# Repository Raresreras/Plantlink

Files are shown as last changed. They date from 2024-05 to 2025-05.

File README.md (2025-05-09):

# Plantlink

## :wrench: English

### Description

Planlink is a special network built to automate and increase efficiency of agriculture, indiferent of its scale. This system is composed from a receiver, which drives an irrigation system that has the capability to extract water from ground(with a better pump) and enrich it using various fertilizers, and a stand-alone sensor, which transmits its own data or relays data from other sensors.
This project has been built for the InfoEducatie 2024 competition.

### Tehnologies used

The following components and modules have been used
  + Arduino Nano
  + 433MHz Transceiver
  + DHT11 Sensor
  + Capacitive sensor to measure the soil humidty
  + TP4056
  + HW668
  + LM2596
  + IRF 840 mosfets
  + BC327 transistors
  + BC337 transistors
  + 20K resistors

Alongisde these components, there also has been used
  + 18650 batteries
  + 1W solar panel 
  + 5V water pump

The case has been 3d printed using PLA, but the use of ABS or PETG is higly recommended due to its superior thermical properties.

## :nut_and_bolt: Romanian

### Descriere

Plantlink este o rețea special concepută pentru automatizarea și eficientizarea agriculturii, indiferent
de dimensiunea acesteia. Acest sistem este format dintr-un receptor, ce conduce un sistem de irigare
ce are capabilitatea de a extrage apă din sol dar și de a-i îmbunătăți proprietățile chimice autonom, și
cel puțin un senzor autonom, ce poate transmite propriile date sau retransmite date de la alte module
senzor.
Acest proiect a fost construit pentru concursul InfoEducatie 2024. 

### Tehnologii

Au fost folosite următoare module și componente
  + Arduino Nano
  + Receptor și transmițător 433MHz
  + DHT11
  + Senzor capacitativ pentru umiditatea solului v2.0
  + TP4056
  + HW668
  + LM2596
  + IRF 840
  + BC327
  + BC337
  + Rezistori cu valoarea 20K

Pe lângă acestea, au mai fost folosite și
  + Baterii 18650
  + Panou solar 1W
  + Pompe de apă 5V

Carcasa este realizată la o imprimantă 3D folosind plastic PLA, dar se recomanda utilizarea ABS-ului sau PETG-ului datorită proprietăților termice superioare.

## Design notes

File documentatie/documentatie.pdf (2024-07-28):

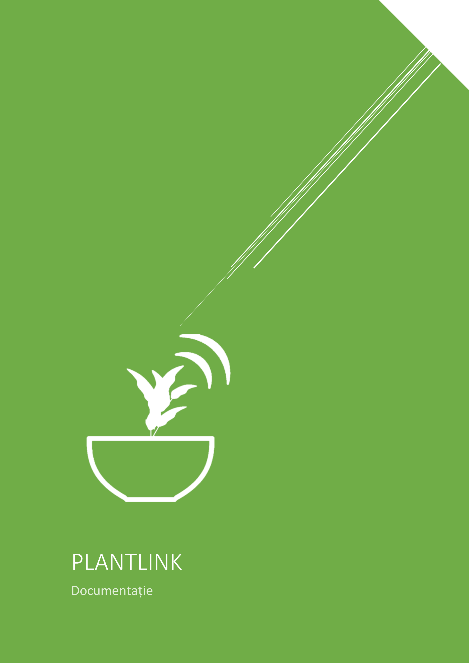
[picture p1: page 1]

# PLANTLINK

Documentație

## Introducere

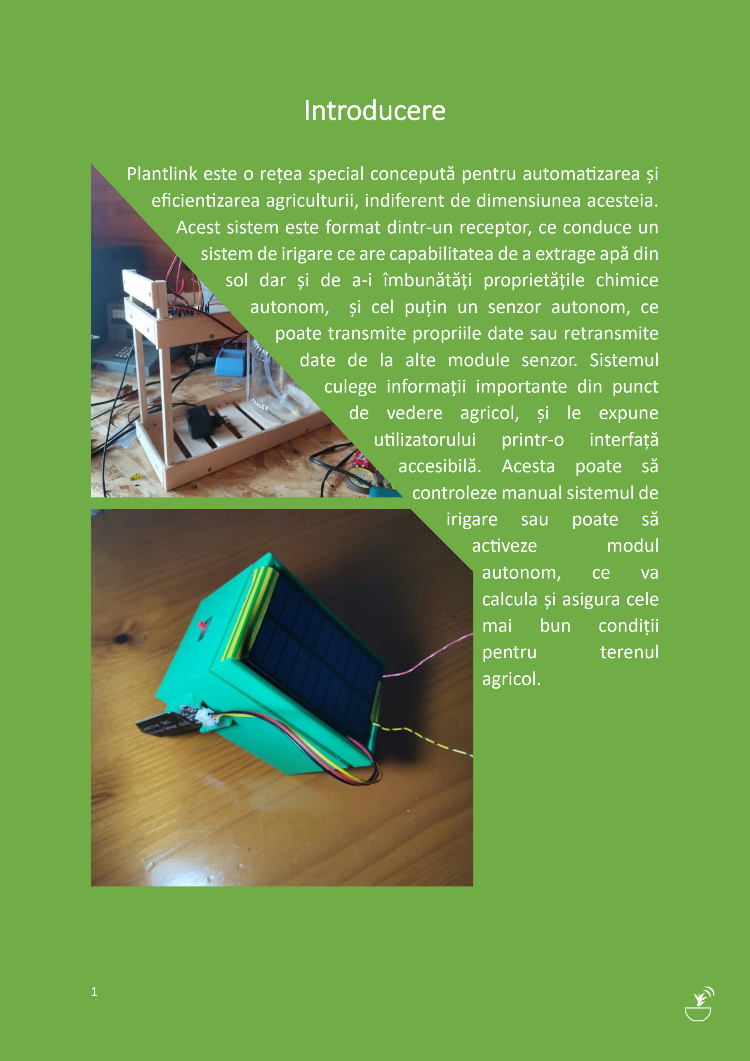
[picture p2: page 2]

Plantlink este o rețea special concepută pentru automatizarea și eficientizarea agriculturii, indiferent de dimensiunea acesteia. Acest sistem este format dintr-un receptor, ce conduce un sistem de irigare ce are capabilitatea de a extrage apă din sol dar și de a-i îmbunătăți proprietățile chimice autonom, și cel puțin un senzor autonom, ce poate transmite propriile date sau retransmite date de la alte module senzor. Sistemul culege informații importante din punct de vedere agricol, și le expune
utilizatorului | printr-o | interfață
accesibilă. Acesta poate să controleze manual sistemul de irigare sau poate să
activeze | modul
autonom, | ce | va
calcula și asigura cele
mai | bun | condiții
pentru | terenul
agricol.

## Senzorul

Senzorul este realizat pe baza unei plăci Arduino Nano, ce este conectată la un senzor DHT11 pentru înregistrarea temperaturii și umidității aerului. Pentru măsurarea umidității solului a fost folosit un modul higrometru capacitativ, datorită rezistenței sale mărite în comparație cu unul rezistiv. Senzorul poate comunica cu alți senzori din rețea sau cu receptorul principal cu ajutorul modulelor de emisie și recepție RF 433 MHz. Datorită frecvenței scăzute (în comparație cu 2.4 GHz, cea a unui modul WI-FI) senzorii au o distanță de comunicare ridicată și au caracteristici de penetrare a obstacolelor ridicate(frunze, copaci, tulpine etc.). Pentru asigurarea alimentării senzorului au fost folosite 2 module HW668, unul pentru stabilizarea tensiunii de la panoul solar și celălalt pentru ridicarea tensiunii de la bateria 18650. Pentru a asigura o exploatare sigură și longevivă a acumulatorului, a fost folosit modulul TP4056. Carcasa a fost realizată în Fusion 360 și a fost imprimată folosind plastic PLA.

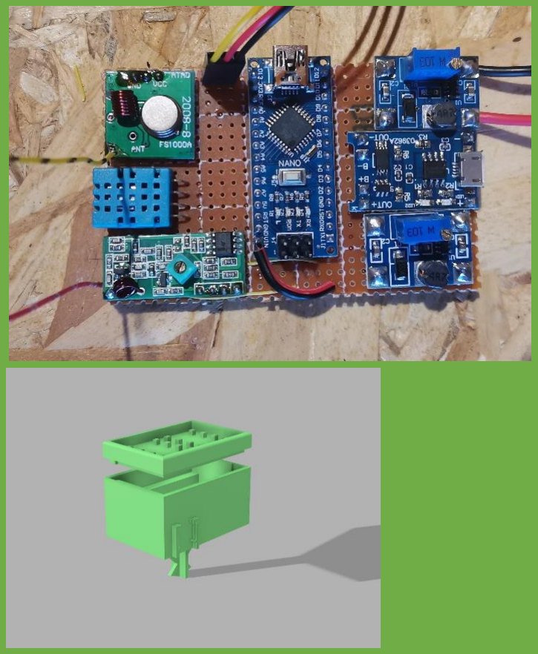
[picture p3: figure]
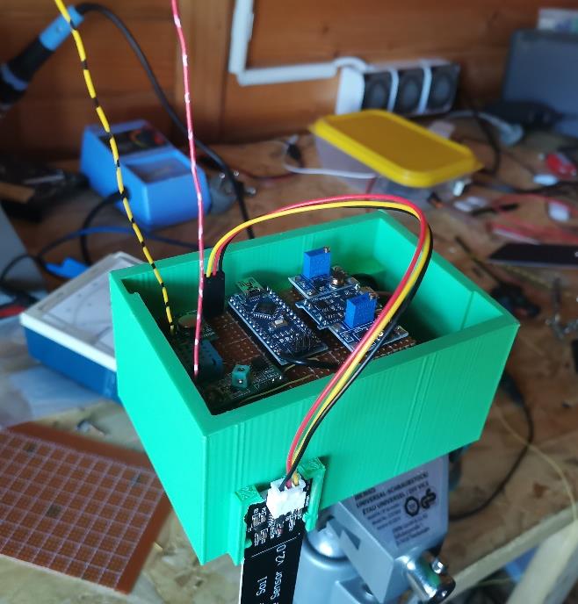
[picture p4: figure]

## Receptorul

La baza receptorului se află o placă Arduino Nano, ce obține nivelul de apă din rezervoare cu ajutorul modulelor higrometrice capacitative și comunică cu modulele senzor cu ajutorul modulelor de emisie și recepție RF 433 MHz. Puterea cu care sunt conduse pompele provine de la un modul de scădere a tensiunii LM2596 pentru a asigura o sursă de energie puternică și eficientă. Pentru a putea acționa motoarele electrice eficient și precis folosim MOSFET-urile cu canal N IRF840 și 2 tranzistori BC327 și BC337 pentru conducerea rapidă a acestuia.

Datele sunt captate de calculator prin ajutorul unui program scris în Python, ce citește un port serial USB prin ajutorul librăriei pySerial și afișează datele într-o interfață GUI creată cu PyQt6. Pentru a folosi acest program, trebuie instalat Python 3.10.5 și pachetul PyQt6.

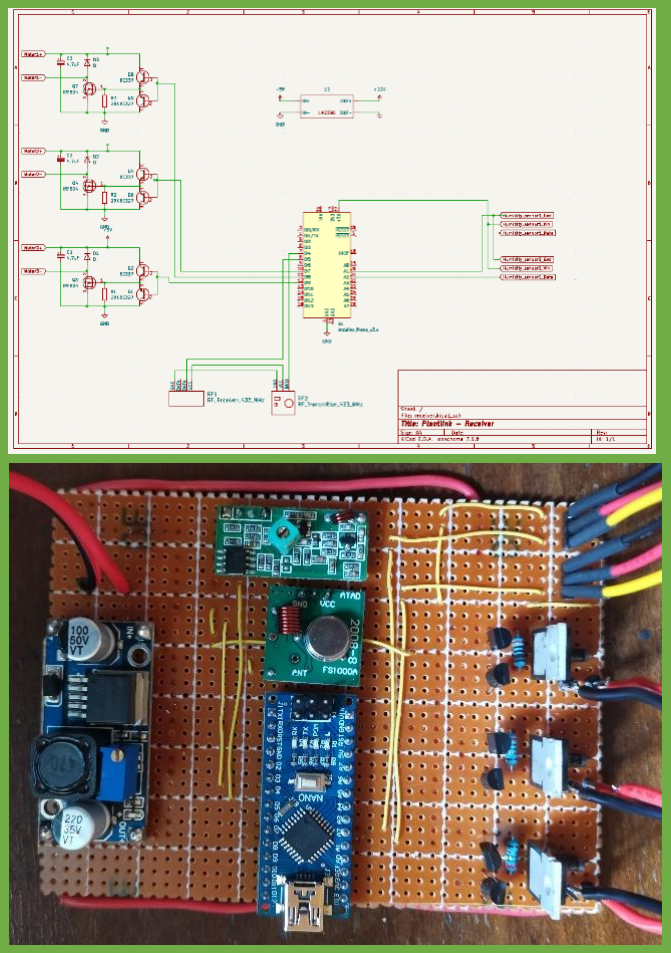
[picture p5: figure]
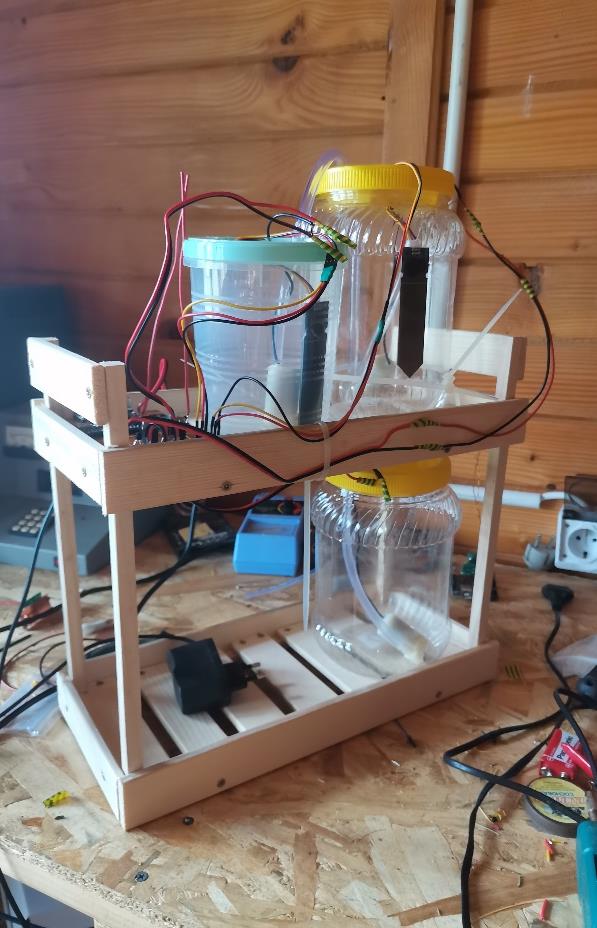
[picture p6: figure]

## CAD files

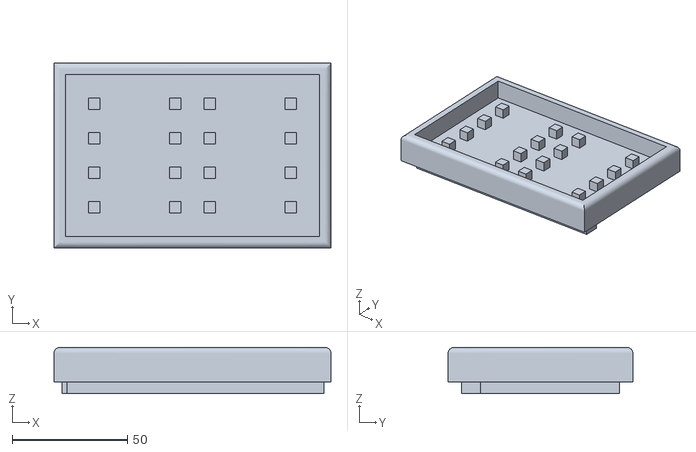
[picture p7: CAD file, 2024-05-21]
sensor v1/Plantlink cap v2.stl
120.0 x 80.0 x 20.0

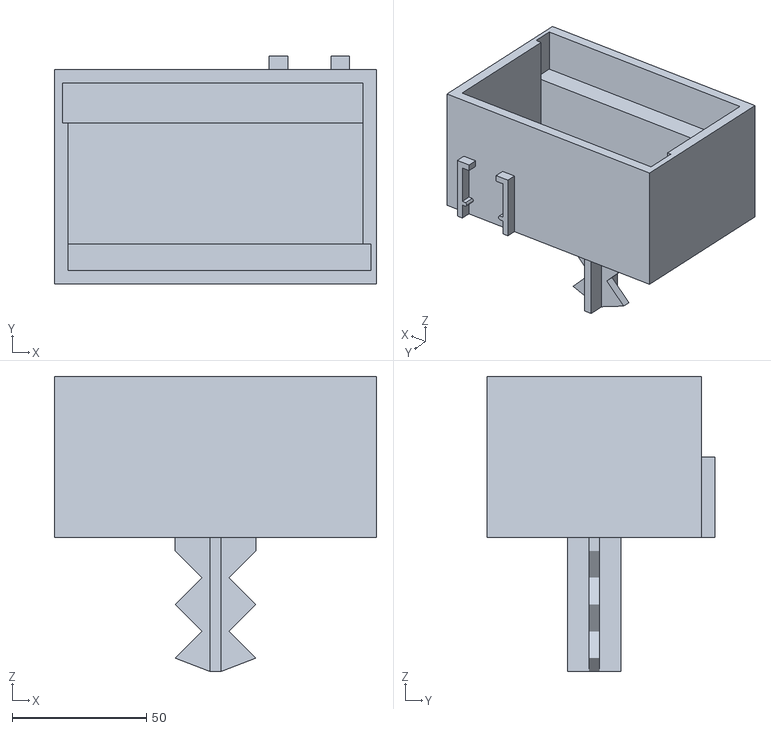
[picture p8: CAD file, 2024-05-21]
sensor v1/Plantlink case v2.stl
120.0 x 85.0 x 110.0

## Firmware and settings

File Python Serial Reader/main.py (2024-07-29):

from PyQt6.QtWidgets import *
from PyQt6.QtCore import *
from PyQt6.QtGui import *
import sys
import serial
import time

data_type = 0
gData = 0

class SerialReaderThread(QThread):
    data_received = pyqtSignal(str)

    def __init__(self, port, baudrate=57600):
        super().__init__()
        self.port = port
        self.baudrate = baudrate
        self.running = True
    
    def run(self):
        try:
            with serial.Serial(self.port, self.baudrate, timeout = 0.1) as ser:
                while self.running:
                    if ser.in_waiting > 0:
                        data = ser.readline()
                        self.data_received.emit(str(data)[:-5][2:])
                        global gData
                        if (gData != 0):
                            time.sleep(1)
                            ser.write((str(gData)+"/n").encode())
                            print(gData)
                            gData = 0
        except serial.SerialException as e:
            self.data_received.emit(f"error: {e}")

    def stop(self):
        self.running = False
        self.wait()

class MainWindow(QMainWindow):
    def __init__(self):
        super().__init__()
        self.setWindowTitle("Plantlink")
        self.start_serial_reader()
        self.setWindowTitle("Plantlink")
        self.setFixedSize(240, 320)

        #Main UI

        mainWidget = QWidget()
        self.setCentralWidget(mainWidget)
        layout = QVBoxLayout()
        mainWidget.setLayout(layout)

        hlayout1 = QHBoxLayout()
        layout.addLayout(hlayout1)
        hlayout1.addWidget(QLabel("Automatic watering"))
        self.automaticWatering = QCheckBox()
        hlayout1.addWidget(self.automaticWatering)

        hlayout2 = QHBoxLayout()
        layout.addLayout(hlayout2)
        hlayout2.addWidget(QLabel("Water level 1 (Main)          "))
        self.waterLevel1Label = QLabel()
        self.waterLevel1Label.setText("waiting data")
        hlayout2.addWidget(self.waterLevel1Label)

        hlayout3 = QHBoxLayout()
        layout.addLayout(hlayout3)
        hlayout3.addWidget(QLabel("Water level 2 (Fertilization)"))
        self.waterLevel2Label = QLabel()
        self.waterLevel2Label.setText("waiting data")
        hlayout3.addWidget(self.waterLevel2Label)

        #Sensor UI

        self.comboBox1 = QComboBox()
        self.comboBox1.addItems(['101', '102', '103'])
        self.comboBox1.activated.connect(self.boardChange)
        layout.addWidget(self.comboBox1)

        self.boardCode = QLabel()
        self.boardCode.setText("Board version: 101")
        self.sensorTemp = QLabel()
        self.sensorTemp.setText("waiting data")
        self.sensorHum = QLabel()
        self.sensorHum.setText("waiting data")
        self.sensorSoilHum = QLabel()
        self.sensorSoilHum.setText("waiting data")

        button1 = QPushButton()
        button1.setText("Fertilization pump")
        button1.setFixedSize(120, 40)
        button1.released.connect(lambda: self.dataChange(1))

        button2 = QPushButton()
        button2.setText("Auxiliary pump")
        button2.setFixedSize(120, 40)
        button2.released.connect(lambda: self.dataChange(2))

        button3 = QPushButton()
        button3.setText("Main pump")
        button3.setFixedSize(120, 40)
        button3.released.connect(lambda: self.dataChange(3))

        layout.addWidget(self.boardCode)
        hlayout4 = QHBoxLayout()
        layout.addLayout(hlayout4)
        hlayout4.addWidget(QLabel("Temperature"))
        hlayout4.addWidget(self.sensorTemp)
        

        hlayout5 = QHBoxLayout()
        layout.addLayout(hlayout5)
        hlayout5.addWidget(QLabel("Humidity"))
        hlayout5.addWidget(self.sensorHum)

        hlayout6 = QHBoxLayout()
        layout.addLayout(hlayout6)
        hlayout6.addWidget(QLabel("Soil humidity"))
        hlayout6.addWidget(self.sensorSoilHum)
        self.targetHumidity = QLineEdit()
        self.targetHumidity.setFixedSize(30, 20)
        self.targetHumidity.setMaxLength(2)
        hlayout6.addWidget(self.targetHumidity)
        layout.addWidget(button1)
        layout.addWidget(button2)
        layout.addWidget(button3)

    def boardChange(self):
        code = str(self.comboBox1.currentText())
        self.boardCode.setText("Board version: "+code)
        self.sensorHum.setText("waiting data")
        self.sensorTemp.setText("waiting data")
        self.sensorSoilHum.setText("waiting data")

    def start_serial_reader(self):
        port = 'COM10'
        self.serial_thread = SerialReaderThread(port)
        self.serial_thread.data_received.connect(self.update_label)
        self.serial_thread.start()

    def dataChange(self, newData):
        global gData
        gData = newData

    def update_label(self, data):
        code = int(self.comboBox1.currentText())
        global data_type

        if data[:3] == 'WL1':
            self.waterLevel1Label.setText(data[4:])
        if data[:3] == 'WL2':
            self.waterLevel2Label.setText(data[4:])

        #automated watering function
        try:
            if ((self.automaticWatering.isChecked()) and (int(data) < int(self.targetHumidity.text())) and (data_type == 83)):
                self.dataChange(3)
        except:
            return

        #data updates
        if data == "72": #ascii for H
            data_type = 72
        if data == "83": #ascii for S
            data_type = 83
        if data == "84": #ascii for T
            data_type = 84
        if data == "86": #ascii for V
            data_type = 86
        if ((data_type == 72) and (data != "72")  and (data[:2] != "WL")):
            self.sensorHum.setText(data)
            data_type = 0
        if ((data_type == 83) and (data != "83")  and (data[:2] != "WL")):
            self.sensorSoilHum.setText(data)
            data_type = 0
        if ((data_type == 84) and (data != "84")  and (data[:2] != "WL")):
            self.sensorTemp.setText(data)
            data_type = 0

    def closeEvent(self, event):
        self.serial_thread.stop()
        event.accept()

app = QApplication(sys.argv)
window = MainWindow()
window.show()

app.exec()

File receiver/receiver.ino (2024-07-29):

#include <VirtualWire.h>

#define pump1 8 //fertilizer pump
#define pump2 7 //water source pump
#define pump3 9 //main pump

#define hum_sen_1 A1 //main water level
#define hum_sen_2 A2 //fertilizer level

//communication
byte message[VW_MAX_MESSAGE_LEN]; //buffer
byte messageLength = VW_MAX_MESSAGE_LEN; //message size
int received_data = 0;

//humidity sensor maximum and minimum values - calibration values
int hum_min1 = 220;
int hum_max1 = 410; 
int hum_min2 = 200; 
int hum_max2 = 480; 


int pump_activ = 0;

void setup() {
  Serial.begin(57600);
  pinMode(pump1, OUTPUT);
  pinMode(pump2, OUTPUT);
  pinMode(pump3, OUTPUT);
  vw_set_rx_pin(5);
  vw_setup(2000);
  vw_rx_start();
}

void loop() {
  Serial.println("WL1_" + String(100 - get_level1())); //Water level 1
  Serial.println("WL2_" + String(100 - get_level2())); //Water level 2
  Serial.println(get_data_transmitter());
  while (Serial.available() > 0) {
    pump_activ = Serial.readStringUntil("/n").toInt();
      if (pump_activ > 0 && pump_activ < 5){
        delay(50);

        if (pump_activ == 1){
          digitalWrite(pump1, HIGH);
          delay(2000);
          digitalWrite(pump1, LOW);
        }
        if (pump_activ == 2){
          digitalWrite(pump2, HIGH);
          delay(2000);
          digitalWrite(pump2, LOW);
        }
        if (pump_activ == 3){
          digitalWrite(pump3, HIGH);
          delay(2000);
          digitalWrite(pump3, LOW);
          pump_activ = 0;
        }
      }
    
    }

}

int get_data_transmitter(){
  if (vw_get_message(message, &messageLength)){
    for (int i = 0; i < messageLength; i++){
      received_data = message[i];
    }
    return received_data;
  }
}

int get_level1(){
  int value = analogRead(hum_sen_1);
  if (value > hum_max1) hum_max1 = value;
  if (value < hum_min1) hum_min1 = value;
  return (float) (value - hum_min1)/(hum_max1 - hum_min1) * 100; 
}

int get_level2(){
  int value = analogRead(hum_sen_2);
  if (value > hum_max2) hum_max2 = value;
  if (value < hum_min2) hum_min2 = value;
  return (float) (value - hum_min2)/(hum_max2 - hum_min2) * 100; 
}

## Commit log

2024-07-18 Update receiver.ino
    fixed previous update
    [receiver.ino]
2024-07-23 new schematic
    [receiver.kicad_sch]
2024-07-29 new calibration values
2024-07-30 Fixed schematic error
    [sensor v1.kicad_sch]
